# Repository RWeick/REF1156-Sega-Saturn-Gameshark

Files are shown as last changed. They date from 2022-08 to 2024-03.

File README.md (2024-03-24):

# REF1156-Sega-Saturn-Gameshark
Everything necessary to produce a Gameshark for the Sega Saturn. The original PCB had a 100 nF capacitor bodged on in addition to the three SMD capacitors. I have added a 4th SMD capacitor to resolve that.

PCB Thickness: 1.6 mm
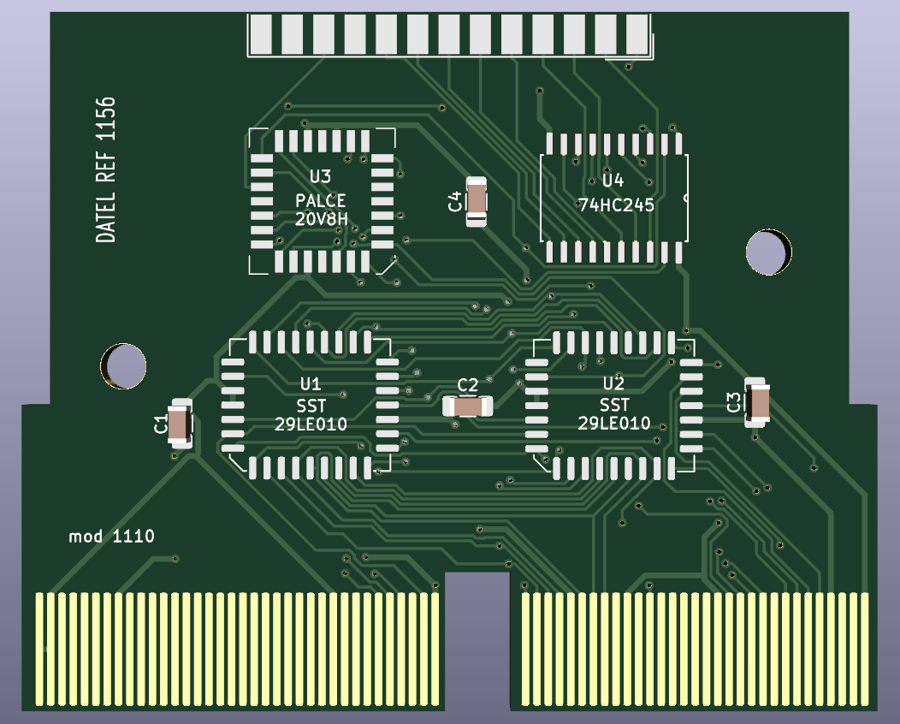
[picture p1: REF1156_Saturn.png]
REF1156


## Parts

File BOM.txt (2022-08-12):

2x SST 29LE010
1x PALCE 20V8H-25JC/4 PLCC 28 Package
1x 74HC245A SOIC-20 Package
3x 100 nF Capacitors 1218 package
1x Ceramic Disc Capacitor 50V 100nF 104 Marking
1x DB25 Parallel Port Adapter, Male

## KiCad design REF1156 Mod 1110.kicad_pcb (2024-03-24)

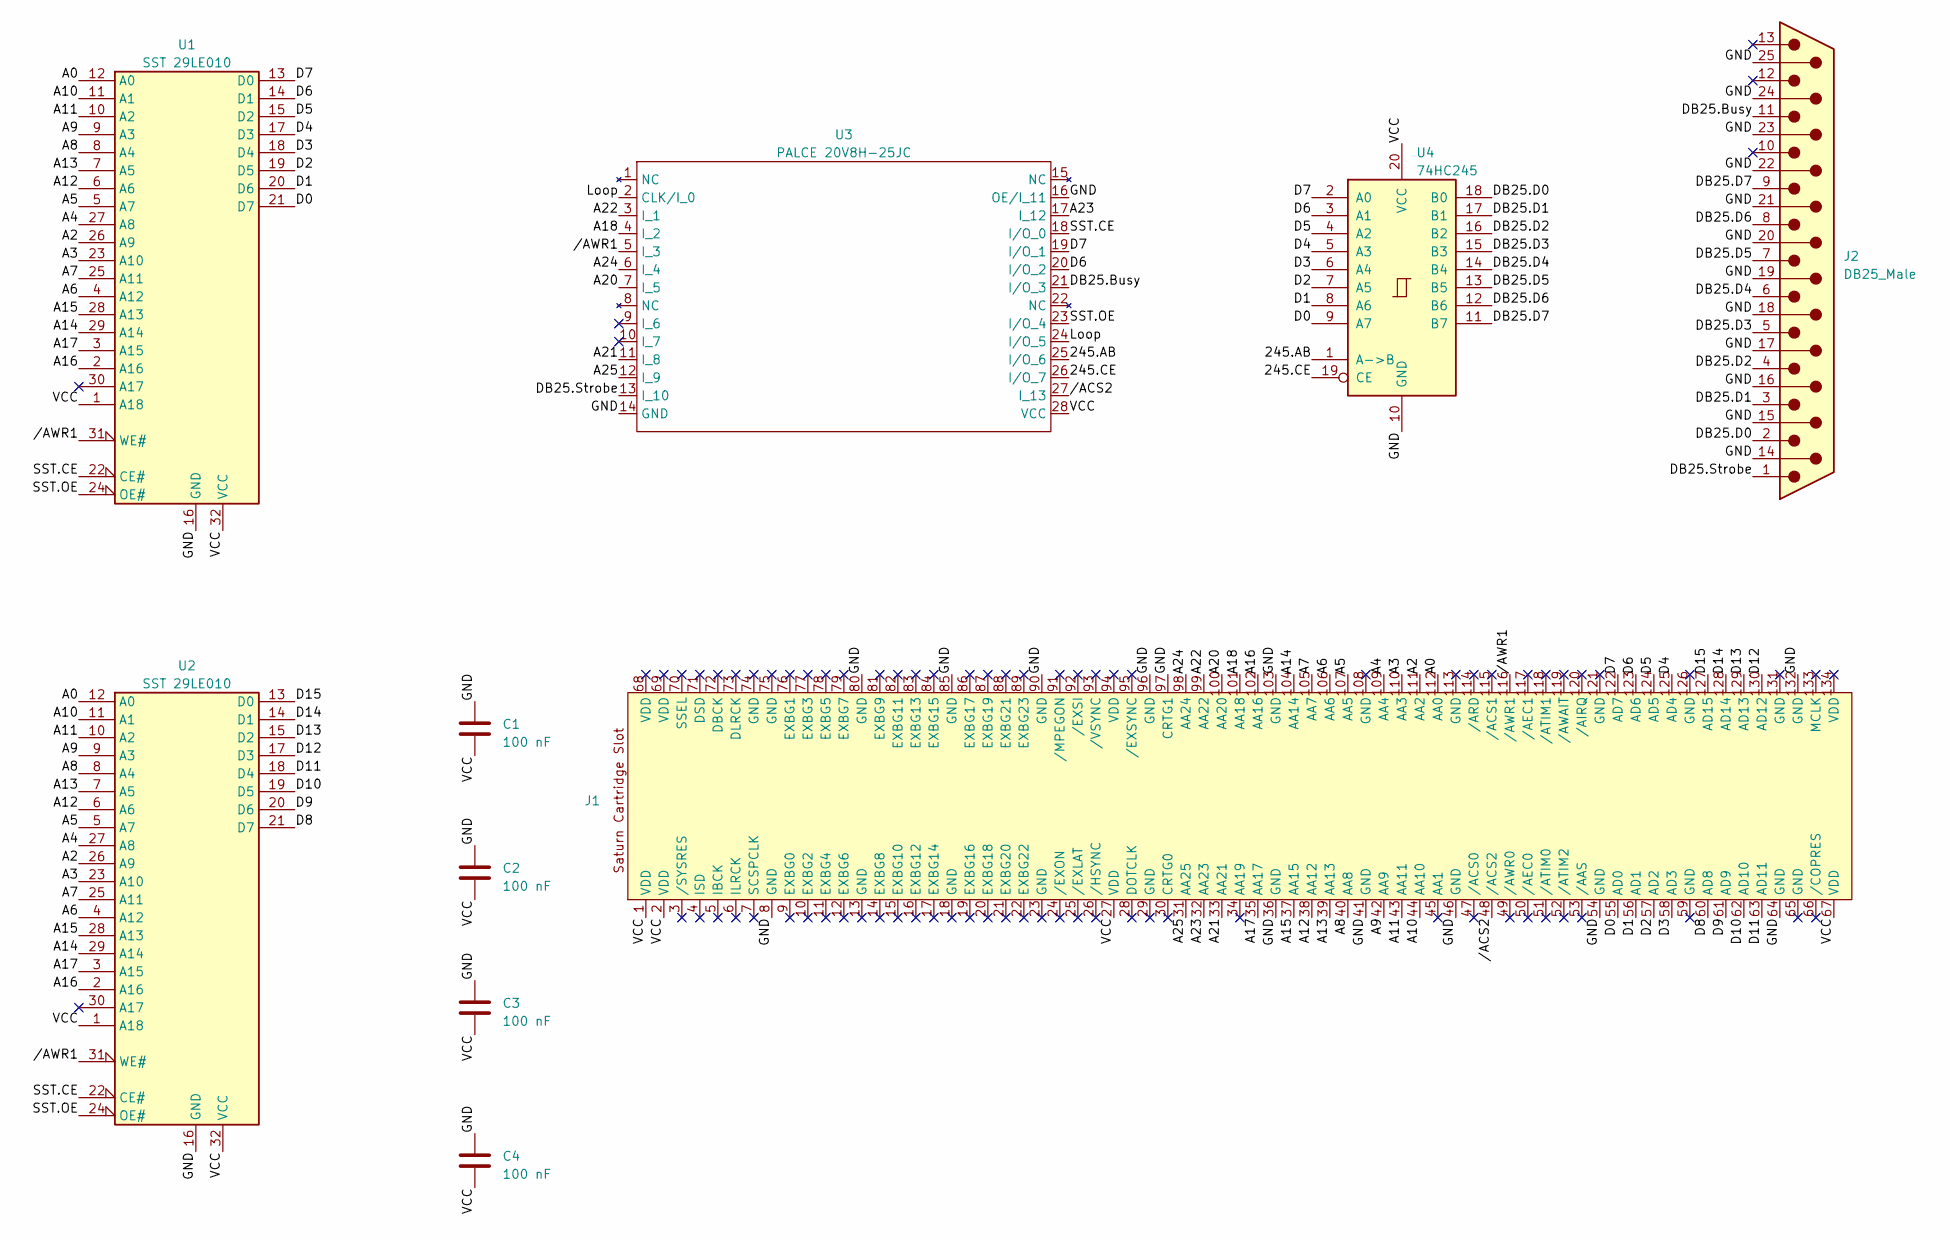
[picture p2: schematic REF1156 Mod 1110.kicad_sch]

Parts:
C1, C2, C3, C4: 100 nF; C_1206_3216Metric_Pad1.33x1.80mm_HandSolder
J1: Cartridge Connector
J2: DB25_Male; DSUB-25_Male_EdgeMount_P2.77mm
U1, U2: SST 29LE010; PLCC-32_11.4x14.0mm_P1.27mm
U3: PALCE 20V8H-25JC; PLCC-28
U4: 74HC245

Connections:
/245.AB: U3.25 (I/O_6), U4.1 (A->B)
/245.CE: U3.26 (I/O_7), U4.19 (CE)
/A0: J1.112 (AA0), U1.12 (A0), U2.12 (A0)
/A2: J1.111 (AA2), U1.26 (A9), U2.26 (A9)
/A3: J1.110 (AA3), U1.23 (A10), U2.23 (A10)
/A4: J1.109 (AA4), U1.27 (A8), U2.27 (A8)
/A5: J1.107 (AA5), U1.5 (A7), U2.5 (A7)
/A6: J1.106 (AA6), U1.4 (A12), U2.4 (A12)
/A7: J1.105 (AA7), U1.25 (A11), U2.25 (A11)
/A8: J1.40 (AA8), U1.8 (A4), U2.8 (A4)
/A9: J1.42 (AA9), U1.9 (A3), U2.9 (A3)
/A10: J1.44 (AA10), U1.11 (A1), U2.11 (A1)
/A11: J1.43 (AA11), U1.10 (A2), U2.10 (A2)
/A12: J1.38 (AA12), U1.6 (A6), U2.6 (A6)
/A13: J1.39 (AA13), U1.7 (A5), U2.7 (A5)
/A14: J1.104 (AA14), U1.29 (A14), U2.29 (A14)
/A15: J1.37 (AA15), U1.28 (A13), U2.28 (A13)
/A16: J1.102 (AA16), U1.2 (A16), U2.2 (A16)
/A17: J1.35 (AA17), U1.3 (A15), U2.3 (A15)
/A18: J1.101 (AA18), U3.4 (I_2)
/A20: J1.100 (AA20), U3.7 (I_5)
/A21: J1.33 (AA21), U3.11 (I_8)
/A22: J1.99 (AA22), U3.3 (I_1)
/A23: J1.32 (AA23), U3.17 (I_12)
/A24: J1.98 (AA24), U3.6 (I_4)
/A25: J1.31 (AA25), U3.12 (I_9)
/D0: J1.55 (AD0), U1.21 (D7), U4.9 (A7)
/D1: J1.56 (AD1), U1.20 (D6), U4.8 (A6)
/D2: J1.57 (AD2), U1.19 (D5), U4.7 (A5)
/D3: J1.58 (AD3), U1.18 (D4), U4.6 (A4)
/D4: J1.125 (AD4), U1.17 (D3), U4.5 (A3)
/D5: J1.124 (AD5), U1.15 (D2), U4.4 (A2)
/D6: J1.123 (AD6), U1.14 (D1), U3.20 (I/O_2), U4.3 (A1)
/D7: J1.122 (AD7), U1.13 (D0), U3.19 (I/O_1), U4.2 (A0)
/D8: J1.60 (AD8), U2.21 (D7)
/D9: J1.61 (AD9), U2.20 (D6)
/D10: J1.62 (AD10), U2.19 (D5)
/D11: J1.63 (AD11), U2.18 (D4)
/D12: J1.130 (AD12), U2.17 (D3)
/D13: J1.129 (AD13), U2.15 (D2)
/D14: J1.128 (AD14), U2.14 (D1)
/D15: J1.127 (AD15), U2.13 (D0)
/DB25.Busy: J2.11, U3.21 (I/O_3)
/DB25.D0: J2.2, U4.18 (B0)
/DB25.D1: J2.3, U4.17 (B1)
/DB25.D2: J2.4, U4.16 (B2)
/DB25.D3: J2.5, U4.15 (B3)
/DB25.D4: J2.6, U4.14 (B4)
/DB25.D5: J2.7, U4.13 (B5)
/DB25.D6: J2.8, U4.12 (B6)
/DB25.D7: J2.9, U4.11 (B7)
/DB25.Strobe: J2.1, U3.13 (I_10)
/GND: C1.1, C2.1, C3.1, C4.2, J1.8 (GND), J1.36 (GND), J1.41 (GND), J1.46 (GND), J1.54 (GND), J1.64 (GND), J1.80 (GND), J1.85 (GND), J1.90 (GND), J1.96 (GND), J1.97 (CRTG1), J1.103 (GND), J1.132 (GND), J2.14, J2.15, J2.16, J2.17, J2.18, J2.19, J2.20, J2.21, J2.22, J2.23, J2.24, J2.25, U1.16 (GND), U2.16 (GND), U3.14 (GND), U3.16 (OE/I_11), U4.10 (GND)
/Loop: U3.2 (CLK/I_0), U3.24 (I/O_5)
/SST.CE: U1.22 (CE#), U2.22 (CE#), U3.18 (I/O_0)
/SST.OE: U1.24 (OE#), U2.24 (OE#), U3.23 (I/O_4)
/VCC: C1.2, C2.2, C3.2, C4.1, J1.1 (VDD), J1.2 (VDD), J1.27 (VDD), J1.67 (VDD), U1.1 (A18), U1.32 (VCC), U2.1 (A18), U2.32 (VCC), U3.28 (VCC), U4.20 (VCC)
//ACS2: J1.48 (/ACS2), U3.27 (I_13)
//AWR1: J1.116 (/AWR1), U1.31 (WE#), U2.31 (WE#), U3.5 (I_3)

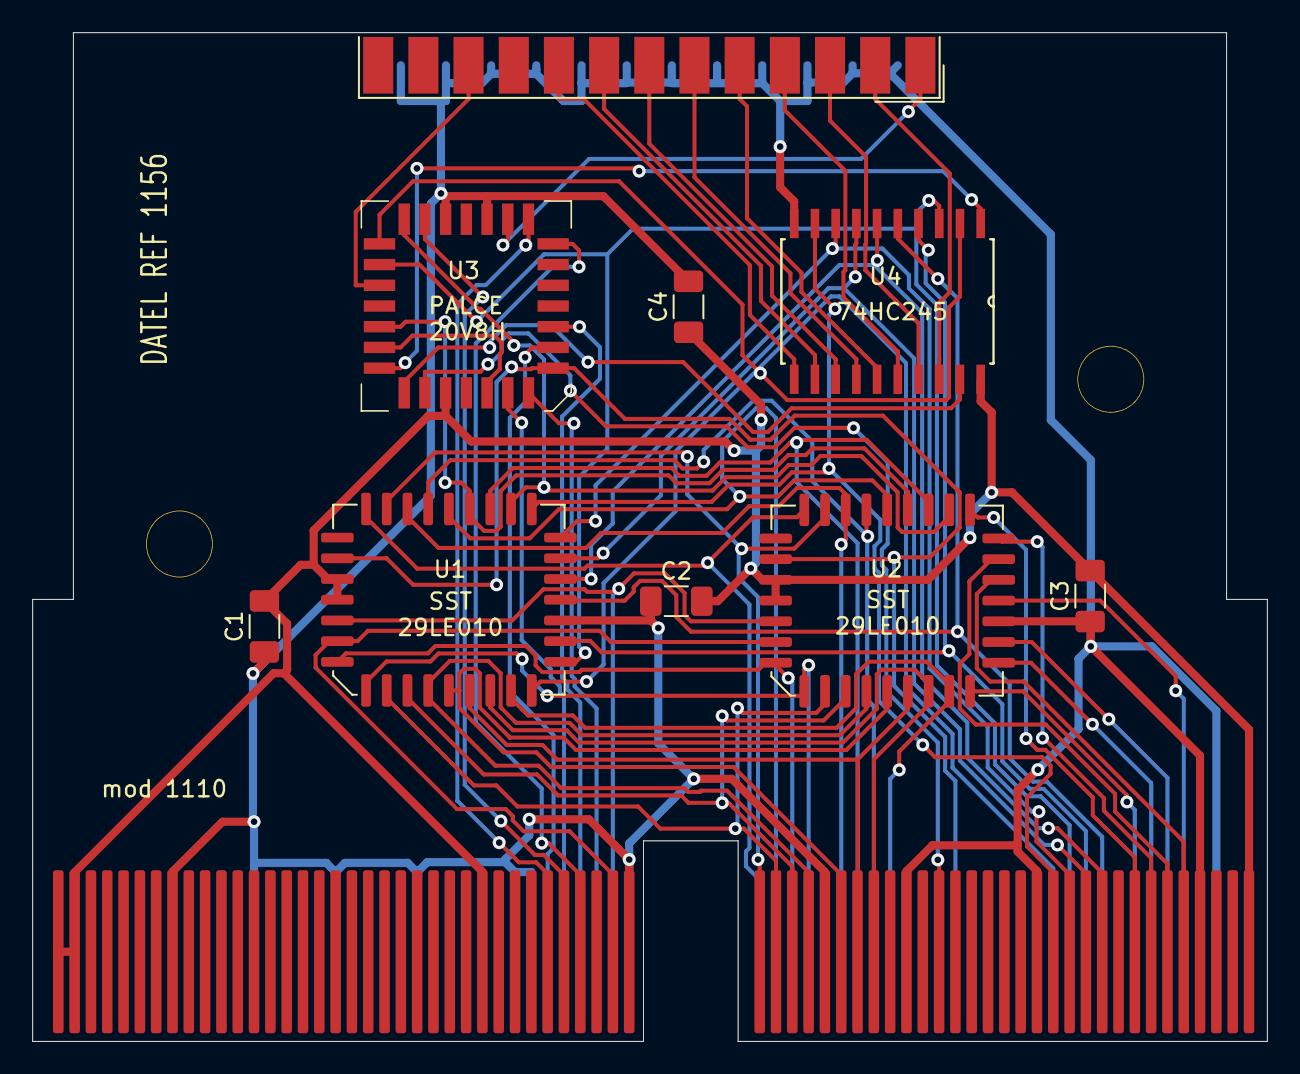
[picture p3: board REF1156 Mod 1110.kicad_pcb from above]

Board: 2 copper layers, 75.7 x 61.8 mm, 11 parts (0 on the bottom side), 59 nets.

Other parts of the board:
Holes: Drill Holes
